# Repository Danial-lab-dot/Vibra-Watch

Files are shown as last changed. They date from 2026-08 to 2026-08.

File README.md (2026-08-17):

 Smart Assistive Watch for the Visually Impaired

A compact wearable smartwatch designed to improve independence and safety for visually impaired users through vibration-based time notification, fall detection, and emergency SOS functionality.

I personally built this since i'm always wondering 'How does blind person do normal human stuff' like eating, driving, reading and specifically know what time is it as they only feel the heat from the sun, not the accurate time. So, I hope with this project, I can eliminate those needs to ask other people, to hear their phone speaking loudly just to tell them what time is it. They can know it just by feeling it, privately.

Features : 

 Vibration-based time notification
 Automatic fall detection
 SOS emergency button
 Bluetooth Low Energy (BLE) connectivity
 Rechargeable Li-Po battery
 High-accuracy DS3231M Real-Time Clock
 Mini vibration motor feedback
 Three tactile control buttons
 
Hardware:

Component	Model
Microcontroller	ESP32-C3 SuperMini
Accelerometer	GY-521 (MPU6050)
RTC	DS3231M
Charging IC	TP4056-42
Voltage Regulator	AP2112K-3.3V
Transistor	2N2222
Diode	1N5819
Battery	3.7V Li-Po
Feedback	Coin Vibration Motor

Future Improvements
Mobile companion application
GPS location tracking
Wireless charging
Heart rate monitoring
Improved battery life

Progress : 
Researching parts needed to make the dream come true - Done
Design a schematic based on the required parts - Done 
Design a Circuit board to match the schematic - Done
Design a 3D Model - Done
Order the parts - Due soon
Assemble the hardware - Coming soon
Testing - Due soon
Final touches - Idk when
The product launching - Soon

Authors : Danial

License : MIT

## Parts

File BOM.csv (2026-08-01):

Reference | Quantity | Part Name | Value/Specification | Package | Description | Estimated Unit Cost (RM) | Estimated Total (RM)
U1 | 1 | ESP32-C3 SuperMini | ESP32-C3 Wi-Fi + BLE | Through-Hole Module | Main Microcontroller | 18.00 | 18.00
U2 | 1 | DS3231M RTC | DS3231M | SOIC-16 | Real-Time Clock | 12.00 | 12.00
U3 | 1 | TP4056 Charger IC | TP4056-42-ESOP8 | ESOP-8 | Li-ion Battery Charger | 4.00 | 4.00
U4 | 1 | GY-521 MPU6050 | GY-521 Module | Module | Accelerometer & Gyroscope | 8.00 | 8.00
U5 | 1 | Voltage Regulator | AP2112K-3.3 | SOT-23-5 | 3.3V LDO Regulator | 3.00 | 3.00
Q1 | 1 | NPN Transistor | 2N2222 | TO-92 | Vibration Motor Driver | 1.00 | 1.00
D1 | 1 | LED | Red LED | 0805 | Status Indicator | 1.00 | 1.00
D4 | 1 | Schottky Diode | 1N5819WS | SOD-323 | Flyback Protection | 1.00 | 1.00
R1 | 1 | Resistor | 1kΩ | 0805 | Motor Driver Base Resistor | 0.10 | 0.10
R2 | 1 | Resistor | 2kΩ | 0805 | LED Current Limiting | 0.10 | 0.10
R3 | 1 | Resistor | 2kΩ | 0805 | LED Current Limiting | 0.10 | 0.10
R5 | 1 | Resistor | 10kΩ | 0805 | Pull-up/Pull-down Resistor | 0.10 | 0.10
R6 | 1 | Resistor | 4.7kΩ | 0805 | I²C SDA Pull-up | 0.10 | 0.10
R7 | 1 | Resistor | 4.7kΩ | 0805 | I²C SCL Pull-up | 0.10 | 0.10
C1 | 1 | Capacitor | 10µF | 0805 | Power Supply Filter | 0.50 | 0.50
C2 | 1 | Capacitor | 10µF | 0805 | Power Supply Filter | 0.50 | 0.50
C3 | 1 | Capacitor | 1µF | 0805 | Voltage Regulator Capacitor | 0.50 | 0.50
C4 | 1 | Capacitor | 1µF | 0805 | Voltage Regulator Capacitor | 0.50 | 0.50
SW1 | 1 | Tactile Switch | 6×6mm | Through-Hole | Time Button | 0.50 | 0.50
SW2 | 1 | Tactile Switch | 6×6mm | Through-Hole | Menu Button | 0.50 | 0.50
SW3 | 1 | Tactile Switch | 6×6mm | Through-Hole | SOS Button | 0.50 | 0.50
M1 | 1 | Coin Vibration Motor | 3V Coin Motor | 10mm | Vibration Feedback | 10.00 | 10.00
BT1 | 1 | Li-Po Battery Connector | 2-Pin JST-PH | Connector | Battery Connection | 2.00 | 2.00
J1 | 1 | Magnetic Charging Connector | 2-Pin 4.00mm Pitch | Connector | Magnetic Charging Interface | 8.00 | 8.00
BAT1 | 1 | Li-Po Battery | 3.7V Rechargeable | Li-Po | Power Source | 25.00 | 25.00
PCB1 | 1 | Custom PCB | 2-Layer FR4 1.0mm ENIG | 36×46mm | Custom PCB Prototype | 282.00 | 282.00
CASE1 | 1 | 3D Printed Enclosure | FDM Printed Black PLA/PETG | Custom | Watch Housing | 16.00 | 16.00

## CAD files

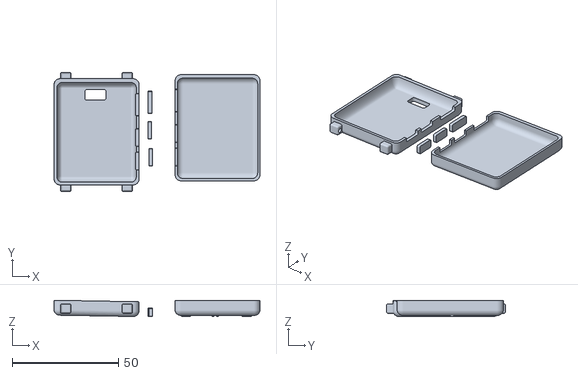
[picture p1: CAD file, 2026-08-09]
VibraTime (2).stl
97.0 x 56.0 x 7.75

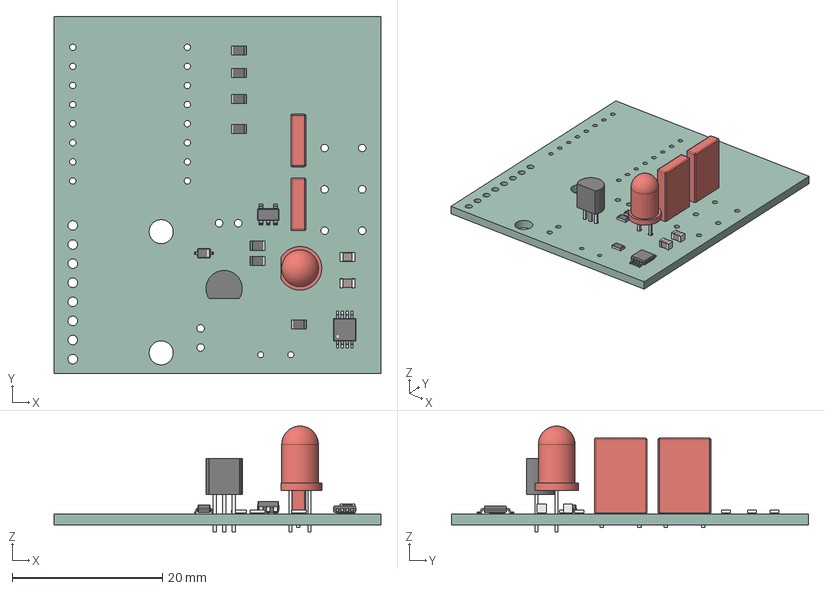
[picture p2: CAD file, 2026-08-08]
Vibra1.step
43.5 x 47.5 x 14.1 mm
SOT-23-5
C_0805_2012Metric x 2
R_0805_2012Metric x 7
TO-92_Inline_Narrow
C_Rect_L70mm_W20mm_P500mm x 2
LED_D5.0mm
D_SOD-323
MSOP-8-1EP_3x3mm_P0.65mm_EP1.68x1.88mm
VibCB14_PCB

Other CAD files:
CAD.dwg

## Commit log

2026-08-01 Add files via upload
    the gerber file for the kicad
    [Vibra1-B_Cu.gbr, Vibra1-B_Mask.gbr, Vibra1-B_Paste.gbr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]
2026-08-01 Add files via upload
    This also include the BOM and GERBER files
    [Vibra1-B_Cu.gbr, Vibra1-B_Mask.gbr, Vibra1-B_Paste.gbr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]
2026-08-01 Add files via upload
    The Gerber files for the PCB Board
    [Vibra1-B_Cu.gbr, Vibra1-B_Mask.gbr, Vibra1-B_Paste.gbr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]
2026-08-01 Add files via upload
    The 3D Design file
    [VibraTime.stl]
